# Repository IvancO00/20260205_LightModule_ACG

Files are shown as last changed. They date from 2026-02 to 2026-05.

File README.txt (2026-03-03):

SETUP INSTRUCTIONS (MKR WAN 1310 as ISP)

WARNING: VOLTAGE LEVELS (3.3V vs 5V)
---------------------------------------------
Your ATmega328PB target microcontroller runs at 5V (according to the schematic).
Your Arduino MKR WAN 1310 runs at 3.3V.

DIRECTLY CONNECTING MKR PINS (3.3V) TO THE 5V BOARD CAN DAMAGE THE MKR!
The SPI lines (MISO, MOSI, SCK) must be level-shifted.

SAFE SOLUTIONS:
1. Use a bidirectional Level Shifter between MKR and Target.
2. OR: Power the target board at 3.3V (instead of 5V) by disconnecting the external 5V source and using the MKR's VCC pin (3.3V) to power the Target's VCC pin. (Note: At 16MHz the 328PB is out of spec at 3.3V, but it often works for flashing).

---------------------------------------------
STEP 1: PREPARE THE MKR WAN 1310
---------------------------------------------
1. Open the classic Arduino IDE.
2. Open the example: File > Examples > 11.ArduinoISP > ArduinoISP.
3. SCROLL THE CODE until you find: `#define RESET 10`.
   ON MKR WAN 1310, pin 10 is often used for other things or can create conflicts (MISO).
   CHANGE that line to: `#define RESET 6` (or another free digital pin).
4. ALSO MODIFY LED PINS:
   Locate `#define LED_HB 9`. Pin 9 is SCK on MKR!
   Change to `#define LED_HB 2` (or any free pin).
   Same for other LEDs if they conflict with pins 8, 9, 10.
5. Upload this sketch to your MKR WAN 1310.

---------------------------------------------
STEP 2: WIRING
---------------------------------------------
MKR WAN 1310 Pin      ->      Target J2 (ISP Connector)
-------------------------------------------------------
VCC (3.3V)            ->      VCC (Pin 3) **ONLY IF POWERING AT 3.3V**
GND                   ->      GND (Pin 5)
Pin 6 (Digital)       ->      RESET (Pin 1)  (The one defined in the sketch)
MOSI (Pin 8)          ->      MOSI (Pin 4)
MISO (Pin 10)         ->      MISO (Pin 2)
SCK  (Pin 9)          ->      SCK  (Pin 6)

*Note on MKR SPI pins: Double check pinout or silkscreen. 
On many MKR boards: MOSI=8, SCK=9, MISO=10.

---------------------------------------------
STEP 3: FLASHING WITH VS CODE
---------------------------------------------
1. Open this project in VS Code.
2. Open the `platformio.ini` file.
3. Modify the line `upload_port = COM11` inserting the real COM port of your MKR.
4. Press the "PlatformIO: Upload" icon (the right arrow in the blue bottom bar, or in the side menu).
5. To set fuses (fix speed): Run "Burn Bootloader" task.

IF ARDUINO LEONARDO IS USED AS PROGRAMMER

MARduInO LEONARDO Pin      ->      Target J2 (ISP Connector)
-------------------------------------------------------
VCC (5V)              ->      VCC 
GND                   ->      GND 
RST  (Pin 10)         ->      RESET (Pin 1)  (The one defined in the sketch)
MOSI (Pin 3)          ->      MOSI (Pin 4)
MISO (Pin 5)          ->      MISO (Pin 2)
SCK  (Pin 6)          ->      SCK  (Pin 6)

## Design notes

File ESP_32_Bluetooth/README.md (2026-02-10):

# PROGETTO CONTROLLER ESP32 BLE -> LIN (iOS & Android)

Questa cartella contiene il firmware per l'ESP32 configurato come **BLE UART Bridge**.
Supporta **iPhone (iOS)** e Android grazie all'uso dello standard Bluetooth Low Energy (Nordic UART Service).

## App Consigliata (iPhone/iOS)
Poiché iOS non supporta il Bluetooth Classico seriale, devi usare un'app BLE UART.
L'app migliore e più semplice è:

**Adafruit Bluefruit LE Connect**
1. Scarica l'app dall'App Store.
2. Apri l'app e cerca il dispositivo **"ESP32_LIN_Control"**.
3. Clicca su **Connect**.
4. Seleziona **UART**.
5. Scrivi i comandi (`R`, `G`, `B`) nel campo di testo e premi Send.

(Alternativa tecnica: **nRF Connect for Mobile**)

## Hardware Richiesto
1.  **ESP32 Dev Board** (es. ESP32-WROOM-32)
2.  **MikroE LIN Click**
3.  **Smartphone** Android (per Bluetooth Classico)

## Collegamenti (ESP32 <-> LIN Click)
| ESP32 Pin | LIN Click Pin | Funzione |
| :--- | :--- | :--- |
| **3.3V** | **3.3V** | Alimentazione logica |
| **5V / VIN** | **5V** | Alimentazione Click (se necessario) |
| **GND** | **GND** | Massa comune |
| **GPIO 17 (TX2)** | **RX** | ESP invia dati al LIN |
| **GPIO 16 (RX2)** | **TX** | ESP riceve dati dal LIN |
| **-** | **RST** | (Lasciare scollegato o HIGH) |
| **GPIO 5** | **CS / EN** | **IMPORTANTE:** Abilita il chip (Chip Select) |

**Nota sul su iPhone
1.  Apri **Bluefruit Connect**.
2.  Connetti a `ESP32_LIN_Control`.
3.  Vai su **UART**.
4.  Digita `R` e invia -> il LED LIN dovrebbe diventare ROSSO.
:

1.  In VS Code, vai su **File > Open Folder...**
2.  Seleziona la cartella `c:\Embedded_Scripts\20260205_LightModule_ACG\ESP_32_Bluetooth`.
3.  Ora vedrai solo i task di PlatformIO relativi all'ESP32.
4.  Collega l'ESP32 via USB.
5.  Fai **Upload**.

## Testing
1.  Accendi tutto.
2.  Sul telefono, attiva il Bluetooth e cerca dispositivi.
3.  Accoppia con **"ESP32_Light_Control"**.
4.  Apri un'app come **"Serial Bluetooth Terminal"**.
5.  Connettiti al dispositivo.
6.  Invia i caratteri `R`, `G`, `B`, `A` per vedere le luci cambiare!

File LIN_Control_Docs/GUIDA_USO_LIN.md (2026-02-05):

# GUIDA ALL'USO DEL CONNETTORE LIN

## 1. Che cos'è?
Il connettore J1 sulla tua scheda permette di controllare le luci da un dispositivo esterno (Computer, Centralina auto, o un altro Arduino) utilizzando il bus **LIN** (12V).

La scheda monta un chip **TJA1028** che converte i segnali LIN (12V) in segnali Seriali (5V) comprensibili dal microcontrollore.

## 2. Collegamenti Hardware (Modulo USB-LIN)
Quando avrai il tuo convertitore USB-LIN in ufficio, collegalo così al connettore **J1**:

| USB-LIN Module | Scheda J1 | Note |
| :--- | :--- | :--- |
| **LIN** (Data) | **Pin 2** (LIN) | Il filo dei dati |
| **GND** | **Pin 1** (GND) | Massa comune (Fondamentale!) |
| **VBAT / 12V** | **Pin 4** (+12V) | Se il modulo fornisce corrente, altrimenti usa alimentatore esterno |

*Attenzione: Controlla la piedinatura del tuo cavo J1 specifico, la tabella sopra è indicativa basata sui nomi standard.*

## 3. Protocollo di Comunicazione
Il codice di esempio fornito (`LIN_main_example.cpp`) utilizza una **Seriale Raw su livello fisico LIN**. 
Non è un protocollo LIN "completo" (con Master/Slave PID, Checksum), ma una semplice trasmissione seriale che sfrutta la robustezza del cavo LIN. È il modo più semplice per iniziare.

**Impostazioni Terminale PC:**
*   **Baudrate:** 19200
*   **Data Bits:** 8
*   **Parity:** None
*   **Stop Bits:** 1

**Comandi disponibili (Da digitare nel terminale):**
*   `R` -> Accende i LED Rossi
*   `G` -> Accende i LED Verdi
*   `B` -> Accende i LED Blu
*   `W` -> Accende i LED Bianchi
*   `A` -> Attiva la modalità Arcobaleno (Animazione)
*   `O` -> Spegne tutto (Off)

## 4. Come caricare il Firmware LIN
Il file principale del progetto è ancora quello originale (Rainbow automatico). Per attivare il controllo via LIN:
1.  Apri il file `src/main.cpp`.
2.  Cancella tutto il contenuto.
3.  Copia il contenuto del file `LIN_Control_Docs/LIN_main_example.cpp`.
4.  Incolla dentro `src/main.cpp`.
5.  Fai **Upload** con PlatformIO.

## 5. Note Tecniche Importanti
Per far funzionare il chip TJA1028, il firmware DEVE tenere alti (HIGH) due pin specifici dell'Arduino:
*   **Pin 2** (PD2) -> Collegato a RSTN del transceiver.
*   **Pin 3** (PD3) -> Collegato a EN del transceiver.

Se questi pin sono LOW, il chip LIN è in modalità "Sleep" e non riceverà nulla. Il codice di esempio gestisce già questa cosa nel `setup()`.

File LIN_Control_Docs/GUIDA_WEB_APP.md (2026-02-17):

# Guida Completa alla Web App Bluetooth (LIN Controller)

Questa guida spiega in dettaglio come funziona il file `index.html` che usi per controllare le luci tramite l'ESP32 e come implementare funzionalità avanzate come gli slider RGB "mixabili".

---

## 1. Come Funziona il File `index.html`

Il file web non è altro che un telecomando virtuale. È diviso in tre strati logici:

### A. La Struttura (`HTML`)
Definisce **cosa c'è** nella pagina. I pulsanti, i testi e gli input (come le caselle di testo o gli slider) vivono qui.
Ogni elemento importante ha un `id` (un nome unico, es. `customCmd`) o un attributo `onclick` (cosa succede quando clicchi).

### B. Lo Stile (`CSS`)
Definisce **come appare**. Colori, bordi e spaziature. Se vedi `.btn-red { background-color: #ff3b30; }`, significa "Tutti gli elementi che hanno la classe 'btn-red' devono essere rossi".

### C. La Logica (`JavaScript`)
Definisce **cosa succede**. È la parte nel blocco `<script>`.
Qui avviene la magia del Bluetooth:
1.  **Chiedi il permesso**: `navigator.bluetooth.requestDevice` apre il menu di sistema per scegliere il dispositivo.
2.  **Ti connetti**: Cerca il "Servizio UART" (una sorta di canale dedicato ai dati seriali).
3.  **Ottieni la Caratteristica**: Cerca la "Caratteristica RX" (la buca delle lettere dove imbucare i messaggi).
4.  **Invii i dati**: `rxCharacteristic.writeValue(data)` trasforma il testo in byte e lo spedisce via radio.

---

## 2. Il Protocollo di Comunicazione
Il codice JavaScript invia delle semplici stringhe di testo che il tuo ESP32 legge e interpreta.

-   **Comando:** `L, <LedIndex>, <Rosso>, <Verde>, <Blu>`
-   **Esempio:** `L,99,4095,0,0\n`
    *   `L`: Comando Luce
    *   `99`: Tutti i LED (oppure 0, 1, 2, 3 per i singoli)
    *   `4095`: Intensità Rosso Massima (12-bit PWM)
    *   `0`: Verde Spento
    *   `0`: Blu Spento
    *   `\n`: Carattere invisibile "a capo" (fondamentale perché l'ESP sappia che il messaggio è finito).

---

## 3. Tutorial: Creare 3 Slider RGB (Mixabili)

Come hai chiesto, ecco come implementare 3 slider (Rosso, Verde, Blu) che lavorano insieme. Se imposti il Rosso al 50% e poi muovi il Verde, il Rosso **deve rimanere** al 50% e non spegnersi.

### Il Problema dei Comandi Semplici
Se fai tre funzioni separate tipo `setRed(val)` che manda `L,99,val,0,0`, ogni volta che muovi uno slider spegni gli altri due colori!
**Soluzione:** Devi leggere TUTTI e tre i valori attuali ogni volta che ne muovi uno.

### Passo 1: Modifica l'HTML
Aggiungi tre slider nel `<body>` (magari sotto ai pulsanti rapidi). Ognuno ha un `id` diverso e chiama la stessa funzione `updateRGB()` quando cambia.

```html
<div class="control-group">
    <h3>Mixer RGB</h3>
    
    <label>Rosso (0-4095)</label>
    <!-- Range da 0 a 4095. onchange = aggiorna quando rilasci (più sicuro per il Bluetooth) -->
    <input type="range" id="sliderR" min="0" max="4095" value="0" onchange="updateRGB()">
    
    <label>Verde (0-4095)</label>
    <input type="range" id="sliderG" min="0" max="4095" value="0" onchange="updateRGB()">
    
    <label>Blu (0-4095)</label>
    <input type="range" id="sliderB" min="0" max="4095" value="0" onchange="updateRGB()">
</div>
```

### Passo 2: Aggiungi la Logica JavaScript
Nel blocco `<script>`, aggiungi questa nuova funzione. Non hai bisogno di variabili globali complesse, perché possiamo leggere il valore attuale direttamente dagli slider HTML ogni volta!

```javascript
/* 
   Questa funzione viene chiamata ogni volta che muovi UNO QUALSIASI degli slider.
   Legge TUTTI e tre i valori attuali e invia un unico comando combinato.
*/
function updateRGB() {
    // 1. Recupera i valori attuali dai tre slider HTML usando i loro ID
    let r = document.getElementById('sliderR').value;
    let g = document.getElementById('sliderG').value;
    let b = document.getElementById('sliderB').value;

    // 2. Costruisci il comando LIN composto
    // Esempio risultato: "L,99,4095,2000,0" (Rosso max, Verde medio, Blu spento)
    let comandoComposto = `L,99,${r},${g},${b}`;

    // 3. Invia tramite Bluetooth
    // window.log è la funzione che scrive nel riquadro bianco in basso
    if(window.log) window.log(`Mixer RGB: R=${r} G=${g} B=${b}`); 
    
    sendCommand(comandoComposto);
}
```

### Passo 3: Sincronizzazione Iniziale (Opzionale)
Quando ti connetti o premi "ALL OFF", gli slider rimangono nella posizione vecchia. Per fare le cose fatte bene, dovresti aggiornare la posizione visiva degli slider quando premi i pulsanti rapidi.

Esempio: modifica il pulsante OFF per resettare anche gli slider.
```html
<button class="btn-off" onclick="resetSlidersAndOff()">ALL OFF</button>
```

E aggiungi questa funzione nel Javascript:
```javascript
function resetSlidersAndOff() {
    // Porta gli slider a zero visivamente
    document.getElementById('sliderR').value = 0;
    document.getElementById('sliderG').value = 0;
    document.getElementById('sliderB').value = 0;
    
    // Manda il comando di spegnimento effettivo
    sendCommand('CLEAR');
}
```

### Consigli per lo Sviluppo
1.  **`onchange` vs `oninput`**:
    *   `oninput`: Lancia l'evento *mentre* trascini. È fluidissimo visivamente ma spara centinaia di comandi Bluetooth al secondo. L'ESP32 potrebbe non starci dietro.
    *   `onchange`: Lancia l'evento solo quando *rilasci* il dito. È molto più stabile. Ua questo all'inizio.

2.  **Debug**: Se non funziona, guarda il riquadro bianco "Log" nella tua app. Se vedi scritto `Sent: L,99,undefined,0,0` significa che hai sbagliato a scrivere l'ID dell'elemento HTML nel ccodice JavaScript.

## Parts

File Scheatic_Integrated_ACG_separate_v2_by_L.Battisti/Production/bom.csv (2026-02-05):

Designator | Footprint | Quantity | Value | LCSC Part #
BTN, GND | TestPoint_Keystone_5015_Micro_Mini | 2 | TestPoint_Keystone_5015_Micro_Mini
C1 | 0805 | 1 | 0.1uF | C476766
C2 | 0805 | 1 | 10 uF | C89827
C3, C4 | 0805 | 2 | 22 pF | C24658
IC1 | QFN50P500X500X90-33N-D | 1 | ATMEGA328PB-MUR | C2651953
J1 | MCON1.2-4 | 1 | Conn_01x04_Pin
J2 | PinSocket_2x03_P2.54mm_Vertical_SMD | 1 | FLASH | C5160818
L1, L2, L3, L4 | LRTB GVSG_OSR | 4 | RGB_LRTB | C2899971
R1 | 0603 | 1 | 1.6k | C351670
R2, R5 | 0603 | 2 | 10k | C98220
R3 | 0603 | 1 | 1k | C491209
TP1, TP10, TP11, TP12, TP2, TP3, TP4, TP5, TP6, TP7, TP8, TP9 | TestPoint_Pad_D2.0mm | 12 | TestPoint
U1 | QFN-32-1EP_5x5mm_P0.5mm_EP3.3x3.3mm_ThermalVias | 1 | TLC5947RHB | C181402
U2 | HVSON8_3X3_NXP | 1 | TJA1028TK/5V0/20/J | C3229277
Y1 | Crystal_SMD_2520-4Pin_2.5x2.0mm | 1 | Crystal_GND24 | C655061

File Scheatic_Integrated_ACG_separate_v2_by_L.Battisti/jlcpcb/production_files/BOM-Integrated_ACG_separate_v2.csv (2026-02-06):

Comment | Designator | Footprint | LCSC | Quantity
0.1uF | C1 | C_0805_2012Metric | C476766 | 1
1.6k | R1 | R_0603_1608Metric | C351670 | 1
10 uF | C2 | C_0805_2012Metric | C89827 | 1
10k | R2,R5 | R_0603_1608Metric | C98220 | 2
1k | R3 | R_0603_1608Metric | C491209 | 1
22 pF | C3,C4 | C_0805_2012Metric | C24658 | 2
ATMEGA328PB-MUR | IC1 | QFN50P500X500X90-33N-D | C2651953 | 1
Crystal_GND24 | Y1 | Crystal_SMD_2520-4Pin_2.5x2.0mm | C655061 | 1
FLASH | J2 | PinSocket_2x03_P2.54mm_Vertical_SMD | C5160818 | 1
TJA1028TK/5V0/20/J | U2 | HVSON8_3X3_NXP | C3229277 | 1
TLC5947RHB | U1 | QFN-32-1EP_5x5mm_P0.5mm_EP3.3x3.3mm_ThermalVias | C181402 | 1
TestPoint_Keystone_5015_Micro_Mini | BTN | TestPoint_Keystone_5015_Micro_Mini |  | 1
TestPoint | TP8 | TestPoint_Pad_D2.0mm |  | 1
TestPoint | TP9 | TestPoint_Pad_D2.0mm |  | 1
TestPoint | TP7 | TestPoint_Pad_D2.0mm |  | 1
TestPoint | TP3 | TestPoint_Pad_D2.0mm |  | 1
TestPoint_Keystone_5015_Micro_Mini | GND | TestPoint_Keystone_5015_Micro_Mini |  | 1
TestPoint | TP4 | TestPoint_Pad_D2.0mm |  | 1
TestPoint | TP6 | TestPoint_Pad_D2.0mm |  | 1
TestPoint | TP5 | TestPoint_Pad_D2.0mm |  | 1
TestPoint | TP12 | TestPoint_Pad_D2.0mm |  | 1
TestPoint | TP11 | TestPoint_Pad_D2.0mm |  | 1
TestPoint | TP10 | TestPoint_Pad_D2.0mm |  | 1
TestPoint | TP1 | TestPoint_Pad_D2.0mm |  | 1
TestPoint | TP2 | TestPoint_Pad_D2.0mm |  | 1
RGB_LRTB | L4 | LRTB GVSG_OSR |  | 1
RGB_LRTB | L3 | LRTB GVSG_OSR |  | 1
RGB_LRTB | L2 | LRTB GVSG_OSR |  | 1
RGB_LRTB | L1 | LRTB GVSG_OSR |  | 1
Conn_01x04_Pin | J1 | MCON1.2-4 |  | 1

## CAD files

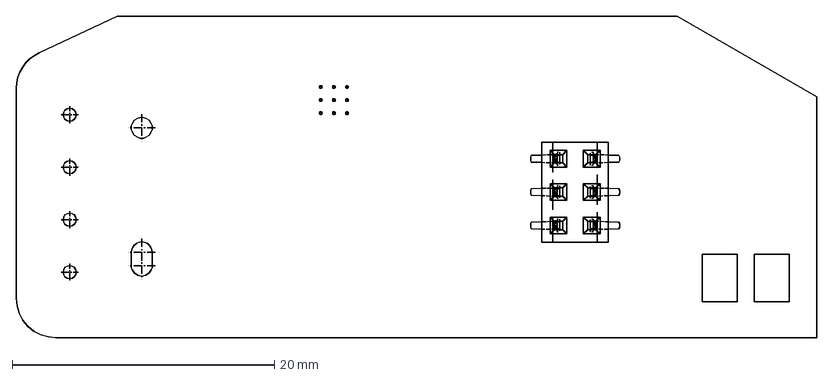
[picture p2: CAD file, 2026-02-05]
Scheatic_Integrated_ACG_separate_v2_by_L.Battisti/DRAWING-20250918.dxf
61.0 x 24.5 mm

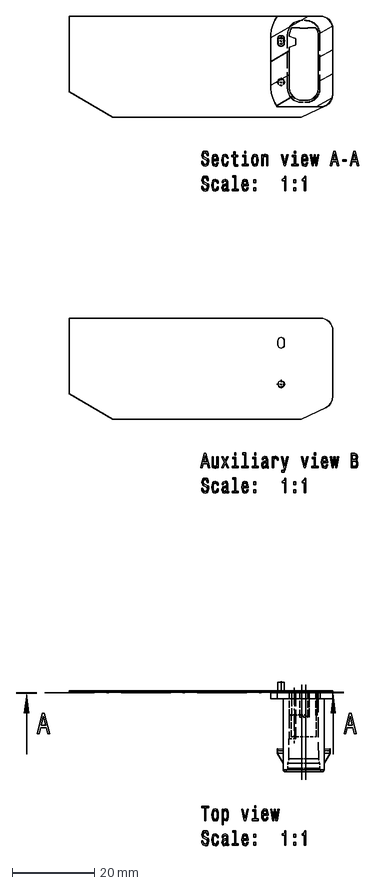
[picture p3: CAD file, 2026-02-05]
Scheatic_Integrated_ACG_separate_v2_by_L.Battisti/DRAWING-20251211.dxf
83.1 x 201.4 mm

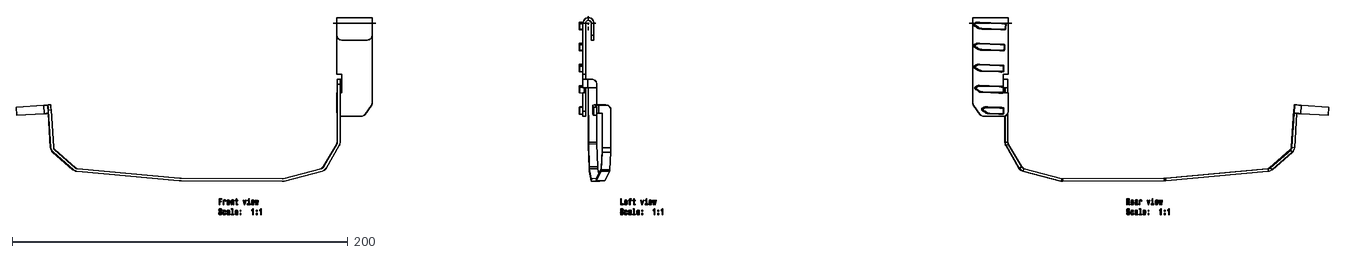
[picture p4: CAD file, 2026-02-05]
Scheatic_Integrated_ACG_separate_v2_by_L.Battisti/DRAWING1.dxf
781.8 x 118.4

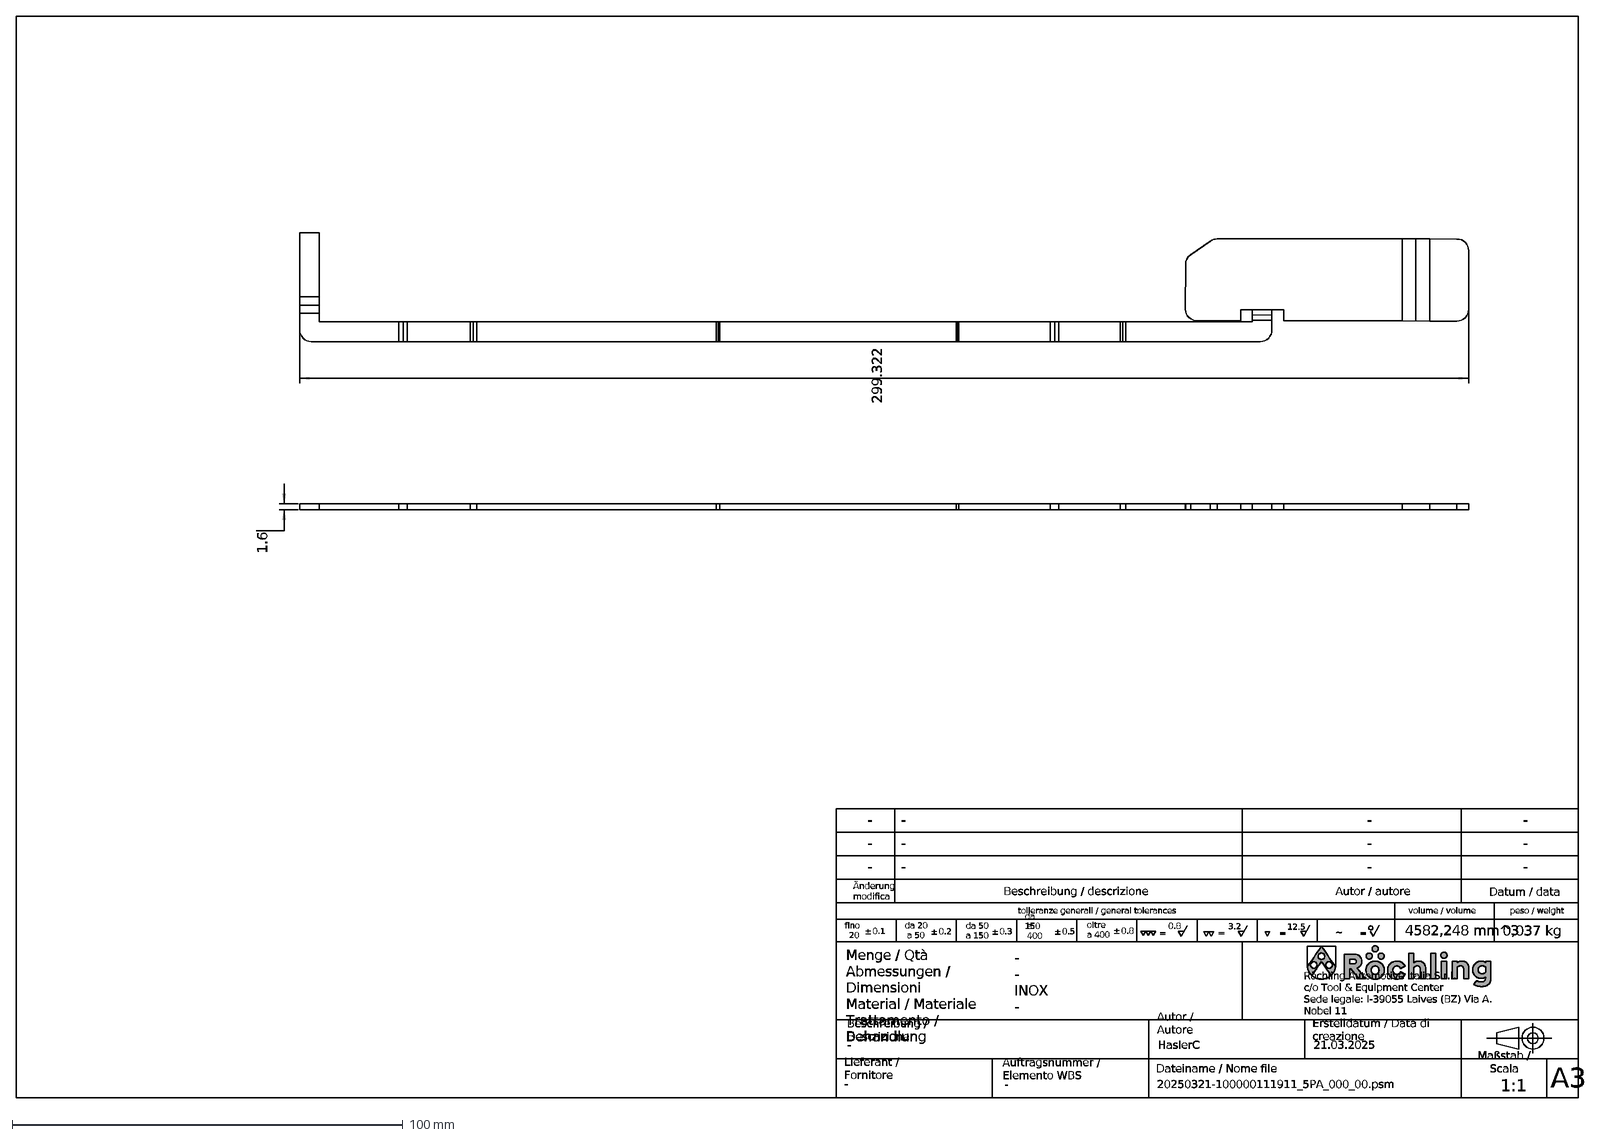
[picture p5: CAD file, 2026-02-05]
Scheatic_Integrated_ACG_separate_v2_by_L.Battisti/20250321-100000111911_5PA_000_00.dxf
1.6
299.322
A3
1:1
Röchling Automotive Italia S.r.l. c/o Tool & Equipment Center Sede legale: I-39055 Laives (BZ) Via A. Nobel 11
21.03.2025
20250321-100000111911_5PA_000_00.psm
Maßstab / Scala
Erstelldatum / Data di creazione
Menge / Qtà Abmessungen / Dimensioni Material / Materiale Trattamento / Behandlung
- - INOX -
HaslerC
-
Beschreibung / Descrizione
Autor / Autore
Lieferant / Fornitore
Dateiname / Nome file
Auftragsnummer / Elemento WBS
Änderung modifica
Beschreibung / descrizione
Autor / autore
Datum / data
0,037 kg
4582,248 mm^3
fino
oltre
da 20
da 50
0.8
da 150
3.2
12.5
±
0.1
0.5
0.3
0.2
=
a 400
20
a 50
a 150
~
peso / weight
volume / volume
tolleranze generali / general tolerances

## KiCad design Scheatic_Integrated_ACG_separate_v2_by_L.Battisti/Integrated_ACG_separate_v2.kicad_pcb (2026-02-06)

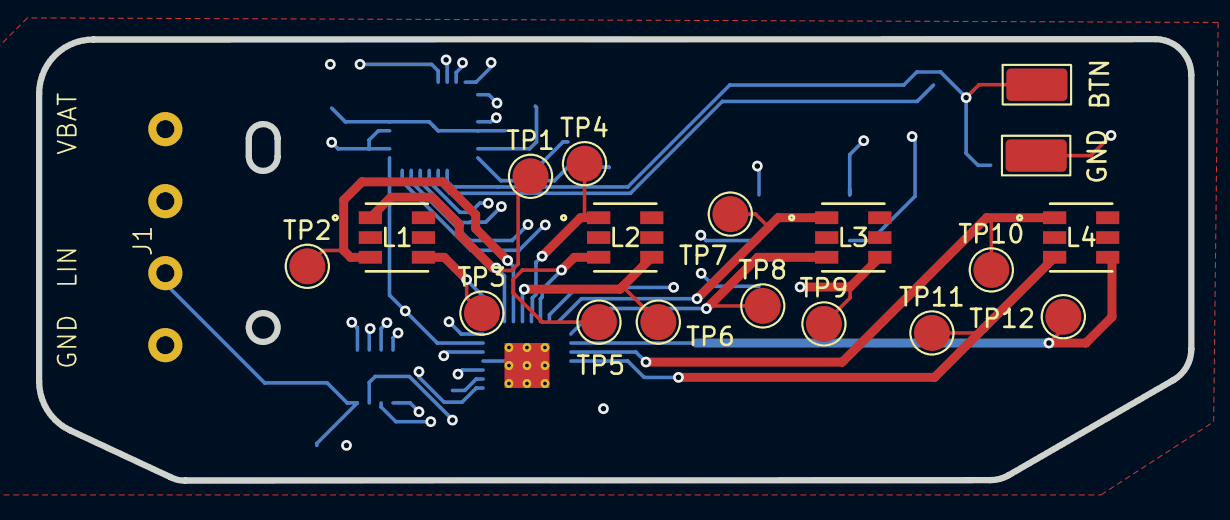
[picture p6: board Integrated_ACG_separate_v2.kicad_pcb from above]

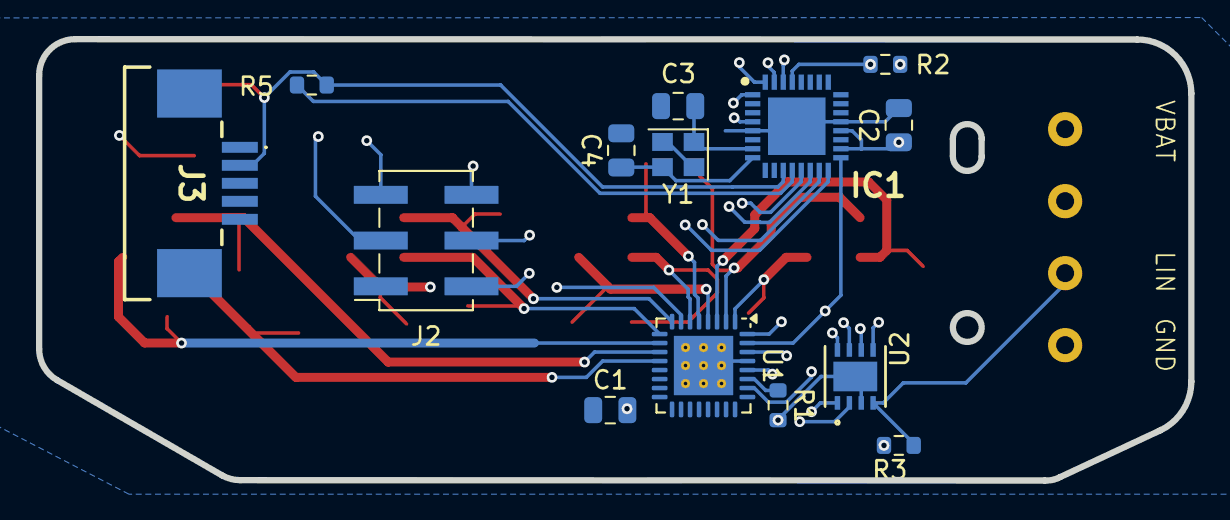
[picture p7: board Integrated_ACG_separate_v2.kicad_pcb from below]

Board: 4 copper layers, 64.0 x 24.5 mm, 33 parts (14 on the bottom side), 31 nets.

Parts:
BTN: TestPoint_Keystone_5015_Micro_Mini
C1: 0.1uF; C_0805_2012Metric
C2: 10 uF; C_0805_2012Metric
C3, C4: 22 pF; C_0805_2012Metric
GND: TestPoint_Keystone_5015_Micro_Mini
IC1: ATMEGA328PB-MUR; QFN50P500X500X90-33N-D
J1: Conn_01x04_Pin; MCON1.2-4
J2: FLASH; PinSocket_2x03_P2.54mm_Vertical_SMD
J3: 84952-5; 849525
L1, L2, L3, L4: RGB_LRTB; LRTB GVSG_OSR
R1: 1.6k; R_0603_1608Metric
R2, R5: 10k; R_0603_1608Metric
R3: 1k; R_0603_1608Metric
TP1, TP2, TP3, TP4, TP5, TP6, TP7, TP8, TP9, TP10, TP11, TP12: TestPoint; TestPoint_Pad_D2.0mm
U1: TLC5947RHB; QFN-32-1EP_5x5mm_P0.5mm_EP3.3x3.3mm_ThermalVias
U2: TJA1028TK/5V0/20/J; HVSON8_3X3_NXP
Y1: Crystal_GND24; Crystal_SMD_2520-4Pin_2.5x2.0mm

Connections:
+5V: C1.2, C2.1, IC1.4 (VCC), IC1.18 (AVCC), IC1.20 (AREF), J2.5, R2.1, U1.28 (VCC), U2.8 (VCC)
+12V: J1.4, L1.2 (A3), L1.5 (A2), L1.6 (A1), L2.2 (A3), L2.5 (A2), L2.6 (A1), L3.2 (A3), L3.5 (A2), L3.6 (A1), L4.2 (A3), L4.5 (A2), L4.6 (A1), R3.1, U2.1 (VBAT)
/LED_Driver/B0: L1.3 (C3), TP2.1, U1.3 (OUT2)
/LED_Driver/B1: L2.3 (C3), TP5.1, U1.6 (OUT5)
/LED_Driver/B2: L3.3 (C3), TP8.1, U1.9 (OUT8)
/LED_Driver/B3: L4.3 (C3), TP11.1, U1.12 (OUT11)
/LED_Driver/BLANK: IC1.13 ((OC1A/PTCXY)_PB1), U1.30 (BLANK)
/LED_Driver/G0: L1.1 (C1), TP1.1, U1.2 (OUT1)
/LED_Driver/G1: L2.1 (C1), TP4.1, U1.5 (OUT4)
/LED_Driver/G2: L3.1 (C1), TP7.1, U1.8 (OUT7)
/LED_Driver/G3: L4.1 (C1), TP10.1, U1.11 (OUT10)
/LED_Driver/LAT: IC1.14 ((~SS0/OC1B/PTCXY)_PB2), U1.26 (XLAT)
/LED_Driver/R0: L1.4 (C2), TP3.1, U1.1 (OUT0)
/LED_Driver/R1: L2.4 (C2), TP6.1, U1.4 (OUT3)
/LED_Driver/R2: L3.4 (C2), TP9.1, U1.7 (OUT6)
/LED_Driver/R3: L4.4 (C2), TP12.1, U1.10 (OUT9)
/uController/EN: IC1.1 ((OC2B/INT1/PTCXY)_PD3), U2.2 (EN)
/uController/LIN: J1.2, R3.2, U2.4 (LIN)
/uController/MISO: IC1.16 ((MISO0/RXD1/PTCXY)_PB4), J2.2
/uController/MOSI: IC1.15 ((MOSI0/TXD1/OC2A/PTCXY)_PB3), J2.4, U1.32 (SIN)
/uController/RST: IC1.29 (PC6_(~RESET)), J2.3, R2.2
/uController/RSTN: IC1.32 (PD2_(PTCXY/INT0/OC3B/OC4B)), U2.7 (RSTN)
/uController/RX: IC1.30 (PD0_(PTCXY/OC3A/RXD0)), U2.5 (RXD)
/uController/SCK: IC1.17 (PB5_(PTCXY/XCK1/SCK0)), J2.6, U1.31 (SCLK)
/uController/TX: IC1.31 (PD1_(PTCXY/OC4A/TXD0)), U2.6 (TXD)
/uController/XTAL1: C3.1, IC1.7 ((XTAL1/TOSC1)_PB6), Y1.1
/uController/XTAL2: C4.1, IC1.8 ((XTAL2/TOSC2)_PB7), Y1.3
GND: C1.1, C2.2, C3.2, C4.2, GND.1, IC1.5 (GND_1), IC1.21 (GND_2), IC1.33 (GND_3), J1.1, J2.1, J3.4, R1.2, U1.29 (GND), U1.33 (PowerPAD), U2.3 (GND), U2.9 (EPAD), Y1.2, Y1.4
unnamed: IC1.12 ((ICP1/CLKO/PTCXY)_PB0), R5.1
unnamed: BTN.1, IC1.11 ((PTCXY/AIN1)_PD7), J3.2, R5.2
unnamed: R1.1, U1.27 (IREF)

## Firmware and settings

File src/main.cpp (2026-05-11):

#include <Arduino.h>
#include "Adafruit_TLC5947.h"

//Limit max current at 30mA --> Max at 50%
#define TOTAL_MAX_POWER 4095*3/2

// --- PIN CONFIGURATION (ATmega328PB) ---
// Based on MiniCore / Standard Arduino Uno mapping for PORTB
#define DATA_PIN  11  // PB3 (MOSI) -> SIN
#define CLOCK_PIN 13  // PB5 (SCK)  -> SCLK
#define LATCH_PIN 10  // PB2 (SS)   -> XLAT
#define BLANK_PIN 9   // PB1        -> BLANK

// --- LIN TRANSCEIVER (TJA1028) PINS ---
// From schematic analysis
#define LIN_EN_PIN   3  // PD3
#define LIN_RST_PIN  2  // PD2 
// RX is D0, TX is D1 (Hardware Serial)

// Number of TLC5947 drivers connected in series (you have 1)
#define NUM_TLC5974 1

// Library instance
Adafruit_TLC5947 tlc = Adafruit_TLC5947(NUM_TLC5974, CLOCK_PIN, DATA_PIN, LATCH_PIN);

// LED Mapping (Channels 0-23)
// LED1: R0, G0, B0 -> Ch 0, 1, 2
// LED2: R1, G1, B1 -> Ch 3, 4, 5
// LED3: R2, G2, B2 -> Ch 6, 7, 8
// LED4: R3, G3, B3 -> Ch 9, 10, 11

void setLedColor(uint8_t ledIndex, uint16_t r, uint16_t g, uint16_t b) {
  // If ledIndex is 99, apply to ALL LEDs
  if(ledIndex == 99) {
     for(int i=0; i<4; i++) {
        setLedColor(i, r, g, b);
     }
     return;
  }

  // Each LED occupies 3 consecutive channels
  // ledIndex: 0 for LED1, 1 for LED2, etc.
  uint16_t baseChannel = ledIndex * 3;
  
  if (baseChannel > 21) return; // Protection (chip has 24 channels, but we only use up to 11)
  if (r+g+b > TOTAL_MAX_POWER) {
    // Scale down to fit max power
    float scale = (float)TOTAL_MAX_POWER / (r + g + b);
    r = (uint16_t)(r * scale);
    g = (uint16_t)(g * scale);
    b = (uint16_t)(b * scale);
  }

  tlc.setPWM(baseChannel + 0, r); // Red
  tlc.setPWM(baseChannel + 1, g); // Green
  tlc.setPWM(baseChannel + 2, b); // Blue
}

void setup() {
  // 1. Initialize LIN Transceiver Control Pins
  pinMode(LIN_EN_PIN, OUTPUT);
  pinMode(LIN_RST_PIN, OUTPUT);
  
  // Create rising edge for RST and Enable HIGH for Normal Mode
  digitalWrite(LIN_RST_PIN, LOW);
  digitalWrite(LIN_EN_PIN, HIGH);
  delay(10);
  digitalWrite(LIN_RST_PIN, HIGH); // Release Reset
  delay(10);

  // 2. Initialize Serial (LIN Bus)
  Serial.begin(19200); // Standard LIN Speed
  Serial.println("LIN_READY");

  // BLANK pin configuration: must be LOW to turn on LEDs
  pinMode(BLANK_PIN, OUTPUT);
  digitalWrite(BLANK_PIN, HIGH); // Start with LEDs off

  // Initialize library
  if (!tlc.begin()) {
    Serial.println("ERR_TLC"); 
  }

  // Enable outputs
  digitalWrite(BLANK_PIN, LOW);
  
  // Initial Test: All Red
  for(int i=0; i<4; i++) setLedColor(i, 4095, 0, 0);
  tlc.write();
  delay(1000);
  
  // Initial Test: All Green
  for(int i=0; i<4; i++) setLedColor(i, 0, 4095, 0);
  tlc.write();
  delay(1000);
  
  // Initial Test: All Blue
  for(int i=0; i<4; i++) setLedColor(i, 0, 0, 4095);
  tlc.write();
  delay(1000);

  // Initial Test: All White
  for(int i=0; i<4; i++) setLedColor(i, 4095, 4095, 4095);
  tlc.write();
  delay(2000);
  
  // Turn off
  for(int i=0; i<4; i++) setLedColor(i, 0, 0, 0);
  tlc.write();
}

// Variables for rainbow effect
uint16_t hue = 0;
void colorWheel(uint8_t ledNum, uint16_t wheelPos) {
  // Helper function to generate rainbow colors
  // wheelPos from 0 to 4095
  uint16_t r, g, b;
  
  // Divide the wheel into 3 parts
  if(wheelPos < 1365) {
    r = (1365 - wheelPos) * 3;
    g = wheelPos * 3;
    b = 0;
  } else if(wheelPos < 2730) {
    wheelPos -= 1365;
    r = 0;
    g = (1365 - wheelPos) * 3;
    b = wheelPos * 3;
  } else {
    wheelPos -= 2730;
    r = wheelPos * 3;
    g = 0;
    b = (1365 - wheelPos) * 3;
  }
  
  setLedColor(ledNum, r, g, b);
}

void blink_white_function(int times, int delay_ms) {
  for (int i = 0; i < times; i++) {
    // Turn on all LEDs (white)
    for(int j=0; j<4; j++) setLedColor(j, 4095, 4095, 4095);
    tlc.write();
    delay(delay_ms);
    
    // Turn off all LEDs
    for(int j=0; j<4; j++) setLedColor(j, 0, 0, 0);
    tlc.write();
    delay(delay_ms);
  }
}

void blink_red_function(int times, int delay_ms) {
  for (int i = 0; i < times; i++) {
    // Turn on all LEDs (red)
    for(int j=0; j<4; j++) setLedColor(j, 4095, 0, 0);
    tlc.write();
    delay(delay_ms);
    
    // Turn off all LEDs
    for(int j=0; j<4; j++) setLedColor(j, 0, 0, 0);
    tlc.write();
    delay(delay_ms);
  }
}

void blink_green_function(int times, int delay_ms) {
  for (int i = 0; i < times; i++) {
    // Turn on all LEDs (green)
    for(int j=0; j<4; j++) setLedColor(j, 0, 4095, 0);
    tlc.write();
    delay(delay_ms);
    
    // Turn off all LEDs
    for(int j=0; j<4; j++) setLedColor(j, 0, 0, 0);
    tlc.write();
    delay(delay_ms);
  }
}

void blink_blue_function(int times, int delay_ms) {
  for (int i = 0; i < times; i++) {
    // Turn on all LEDs (blue)
    for(int j=0; j<4; j++) setLedColor(j, 0, 0, 4095);
    tlc.write();
    delay(delay_ms);
    
    // Turn off all LEDs
    for(int j=0; j<4; j++) setLedColor(j, 0, 0, 0);
    tlc.write();
    delay(delay_ms);
  }
}

void turn_off_all_leds() {
  for(int i=0; i<4; i++) setLedColor(i, 0, 0, 0);
  tlc.write();
}

void chargingEffect() {
  turn_off_all_leds(); // Turn off all LEDs after blinking

  blink_red_function(3, 200); // Blink all LEDs red 3 times at the start of charging

  // Simulate battery charging: dim each LED up to max, then move to next
  int led = 3;
  uint16_t brightness = 0;

  while (led >= 0) {
    brightness += 50;
    setLedColor(led, 0, brightness, 0); // Green color
    tlc.write();
    delay(10);
    if (brightness > 4095-50) {
      setLedColor(led, 0, 4095, 0); // Green color
      brightness = 0;
      led--;

      if (led == -1) {
        delay(500); // Short pause before blinking
        blink_white_function(5, 200); // Blink all LEDs 3 times at the end of charging
        
        turn_off_all_leds(); // Turn off all LEDs after blinking
        delay(500); // Short pause before next effect
      };
    };
  };
};

// Global buffer for LIN/Serial parsing
String inputString = "";
boolean stringComplete = false;

void processLinCommand() {
  if (stringComplete) {
    // Expected format: "L,idx,r,g,b"
    // Example: "L,0,4095,0,0" (Red on LED 0)
    // Example: "L,99,0,0,4095" (Blue on ALL LEDs)
    // Example: "CHARGE" (Run charging effect once)
    
    if (inputString.startsWith("L,")) {
      // Remove prefix
      String params = inputString.substring(2);
      
      // Manual parsing
      int firstComma = params.indexOf(',');
      int secondComma = params.indexOf(',', firstComma + 1);
      int thirdComma = params.indexOf(',', secondComma + 1);
      
      if (firstComma > 0 && secondComma > 0 && thirdComma > 0) {
        int idx = params.substring(0, firstComma).toInt();
        int r = params.substring(firstComma + 1, secondComma).toInt();
        int g = params.substring(secondComma + 1, thirdComma).toInt();
        int b = params.substring(thirdComma + 1).toInt();
        
        setLedColor(idx, r, g, b);
        tlc.write();
      }
    }
    else if (inputString == "CHARGE") {
        chargingEffect();
    }
    else if (inputString == "CLEAR") {
        turn_off_all_leds();
    }
    else if (inputString == "TEST") {
        // Run a quick test sequence
        for(int i=0; i<4; i++) setLedColor(i, 4095, 0, 0); // Red
        tlc.write();
        delay(500);
        for(int i=0; i<4; i++) setLedColor(i, 0, 4095, 0); // Green
        tlc.write();
        delay(500);
        for(int i=0; i<4; i++) setLedColor(i, 0, 0, 4095); // Blue
        tlc.write();
        delay(500);
        for(int i=0; i<4; i++) setLedColor(i, 4095, 4095, 4095); // White
        tlc.write();
        delay(1000);
        turn_off_all_leds(); // Turn off after test
    }

    else if (inputString == "CHARGE_CONTINUOUS") {
        while(inputString != "CLEAR") { // Run charging effect continuously until "CLEAR" command is received
            chargingEffect();
        }
    }
    
    // Clear buffer
    inputString = "";
    stringComplete = false;
  }
}

void serialEvent() {
  while (Serial.available()) {
    char inChar = (char)Serial.read();
    if (inChar == '\n') {
      stringComplete = true;
    } else if (inChar != '\r') {
      inputString += inChar;
    }
  }
}

void loop() {
  // Check for new commands
  serialEvent(); // Manually calling ensures it runs even if platformio setup differs
  processLinCommand();

  // Note: if chargingEffect() is called here unconditionally, it will block 
  // command processing. You might want to remove it or only call it on command.
  // chargingEffect(); 
  
  delay(20);
}

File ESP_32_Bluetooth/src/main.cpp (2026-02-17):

#include <Arduino.h>
#include <BLEDevice.h>
#include <BLEServer.h>
#include <BLEUtils.h>
#include <BLE2902.h>

// PIN Definitions
// TX2 (GPIO 17) -> RX of LIN Click
// RX2 (GPIO 16) -> TX of LIN Click
#define RXD2 16
#define TXD2 17
// Pin to enable LIN Click (CS/EN)
#define LIN_ENABLE_PIN 5 

// UUIDs for Nordic UART Service (Widely supported by iOS Apps like Bluefruit Connect)
#define SERVICE_UUID           "6E400001-B5A3-F393-E0A9-E50E24DCCA9E" 
#define CHARACTERISTIC_UUID_RX "6E400002-B5A3-F393-E0A9-E50E24DCCA9E"
#define CHARACTERISTIC_UUID_TX "6E400003-B5A3-F393-E0A9-E50E24DCCA9E"

BLEServer *pServer = NULL;
BLECharacteristic *pTxCharacteristic;
bool deviceConnected = false;
bool oldDeviceConnected = false;

// Callbacks for Connect/Disconnect
class MyServerCallbacks: public BLEServerCallbacks {
    void onConnect(BLEServer* pServer) {
      deviceConnected = true;
      Serial.println("Device Connected");
    };

    void onDisconnect(BLEServer* pServer) {
      deviceConnected = false;
      Serial.println("Device Disconnected");
    }
};

// Callbacks for receiving data from Phone
class MyCallbacks: public BLECharacteristicCallbacks {
    void onWrite(BLECharacteristic *pCharacteristic) {
      std::string rxValue = pCharacteristic->getValue();

      if (rxValue.length() > 0) {
        String cmd = "";
        Serial.print("Received from Phone: ");
        for (int i = 0; i < rxValue.length(); i++) {
          Serial.print(rxValue[i]);
          cmd += (char)rxValue[i];
        }
        Serial.println();
        
        // Ensure command ends with newline for LIN protocol
        if (!cmd.endsWith("\n")) {
           cmd += "\n";
        }
        
        // Forward to LIN Bus
        Serial2.print(cmd);
      }
    }
};

void sendLinCommand(String cmd) {
    if (!cmd.endsWith("\n")) cmd += "\n";
    Serial2.print(cmd);
    Serial.println("LIN TX: " + cmd);
    delay(500); // Small delay between test commands
}

void setup() {
  Serial.begin(115200);

  // 1. Setup LIN Enable Pin
  if (LIN_ENABLE_PIN != -1) {
    pinMode(LIN_ENABLE_PIN, OUTPUT);
    digitalWrite(LIN_ENABLE_PIN, HIGH);
  }

  // 2. Setup LIN Serial (UART2)
  Serial2.begin(19200, SERIAL_8N1, RXD2, TXD2);
  
  delay(1000); // Wait for LIN transceiver stabilization

  // --- LIN CONNECTION TEST ON BOOT ---
  Serial.println("Starting LIN Test Sequence...");
  sendLinCommand("L,99,4095,0,0"); // All RED
  sendLinCommand("L,99,0,4095,0"); // All GREEN
  sendLinCommand("L,99,0,0,4095"); // All BLUE
  sendLinCommand("CLEAR");         // All OFF
  Serial.println("LIN Test Sequence Complete.");

  // 3. Setup BLE
  BLEDevice::init("ESP32_LIN_Control_Ivan"); // Device Name

  // Create Server
  pServer = BLEDevice::createServer();
  pServer->setCallbacks(new MyServerCallbacks());

  // Create Service
  BLEService *pService = pServer->createService(SERVICE_UUID);

  // Create TX Characteristic (ESP -> Phone)
  pTxCharacteristic = pService->createCharacteristic(
                    CHARACTERISTIC_UUID_TX,
                    BLECharacteristic::PROPERTY_NOTIFY
                  );
  pTxCharacteristic->addDescriptor(new BLE2902());

  // Create RX Characteristic (Phone -> ESP)
  BLECharacteristic *pRxCharacteristic = pService->createCharacteristic(
                       CHARACTERISTIC_UUID_RX,
                       BLECharacteristic::PROPERTY_WRITE
                     );
  pRxCharacteristic->setCallbacks(new MyCallbacks());

  // Start Service
  pService->start();

  // Start Advertising
  BLEAdvertising *pAdvertising = BLEDevice::getAdvertising();
  pAdvertising->addServiceUUID(SERVICE_UUID);
  pAdvertising->setScanResponse(true);
  pAdvertising->setMinPreferred(0x06);  // funtions that help with iPhone connections issue
  pAdvertising->setMinPreferred(0x12);
  BLEDevice::startAdvertising();
  Serial.println("Waiting for iPhone connection...");
}

void loop() {
  // If we receive data from LIN -> Send to Phone
  if (Serial2.available()) {
     int byte = Serial2.read();
     if (deviceConnected) {
        uint8_t val = (uint8_t)byte;
        pTxCharacteristic->setValue(&val, 1);
        pTxCharacteristic->notify();
     }
  }

  // Disconnection handling (Restart advertising)
  if (!deviceConnected && oldDeviceConnected) {
      delay(500); 
      pServer->startAdvertising(); 
      Serial.println("Restart advertising...");
      oldDeviceConnected = deviceConnected;
  }
  // Connection handling
  if (deviceConnected && !oldDeviceConnected) {
      oldDeviceConnected = deviceConnected;
  }
}

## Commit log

2026-02-05 4 RGB led control w/ arduino MKR WAN 1310 Bootloader
2026-02-05 add schematic
    [20250321-100000111911_5PA_000_00.dxf, DRAWING-20250918.dxf, DRAWING-20251211.dxf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]
2026-02-05 Refreash folder
    [20250321-100000111911_5PA_000_00.dxf, DRAWING-20250918.dxf, DRAWING-20251211.dxf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]
2026-02-05 NB! Setlight masimum power to 60%. Current problem on LED driver on pure whight if not
    [main.cpp]
2026-02-06 Add new LED functions and update charging effect
    [BOM-Integrated_ACG_separate_v2.csv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]
2026-02-12 fix arduino leonardo ISP programmerscript
    [ArduinoMKRWAN1310_ISP.ino, main.cpp]
2026-02-17 add white button to index.html
2026-02-17 Accept all the devices
2026-02-17 change onimput into one charge. Connection limit
2026-02-17 add charge effect and test LEDs button
2026-03-03 Update Readme adding connections to flash the light module using the leonardo board
